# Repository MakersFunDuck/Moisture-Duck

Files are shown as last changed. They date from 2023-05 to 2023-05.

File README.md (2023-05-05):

# Moisture-Duck
ATtiny13A Resistive Soil Sensor for Duck Lovers

Moisture-Duck helps you keep track of your plants' soil moisture and alerts you if they need watering. It utilizes the resistance measurement technique to gauge soil moisture levels. Two probes, in combination with the substrate, constitute a variable resistor. Greater soil moisture translates to improved conductivity and decreased electrical resistance. With the addition of a 12k fixed resistor, the system creates a voltage divider. The microcontroller's ADC measures this voltage. The design is inspired by the SparkFun Soil Moisture Sensor.

Description:
------------
The Moisture Duck is a device that measures soil moisture and emits an acoustic and optical signal if the soil is too dry. The device is based on ATtiny13, which spends most of its time in sleep mode and wakes up every eight seconds to take measurements. It can also be activated by pressing the TEST button, and the correct threshold value can be set by turning the potentiometer. To calibrate the device, it should be placed in dry soil and the potentiometer should be adjusted until the alarm is triggered. The device is compiled using MicroCore and default settings should be left unchanged. Arduino core functions and libraries are not used, and the makefile can be used for compilation without Arduino IDE. The fuse settings are -U lfuse:w:0x3b:m -U hfuse:w:0xff:m.

Compiling and Uploading:
------------

You can program the ATtiny either before soldering using an SOP adapter, or after soldering using ICSP pins. The AVR Programmer Adapter can help with this.
If using the Arduino IDE

    Make sure you have installed MicroCore.
    Go to Tools -> Board -> MicroCore and select ATtiny13.
    Go to Tools and choose the following board options:
        Clock: 128 kHz internal osc.
        BOD: BOD disabled
        Timing: Micros disabled
    Connect your programmer to your PC and to the ATtiny.
    Go to Tools -> Programmer and select your ISP programmer (e.g. USBasp).
    Go to Tools -> Burn Bootloader to burn the fuses.
    Open main.ino and click Upload.

If using the precompiled hex-file

    Make sure you have installed avrdude.
    Connect your programmer to your PC and to the ATtiny.
    Open a terminal.
    Navigate to the folder with the hex-file.
    Execute the following command (if necessary replace "usbasp" with the programmer you use):

    avrdude -c usbasp -p t13 -U lfuse:w:0x3b:m -U hfuse:w:0xff:m -U flash:w:main.hex

If using the makefile (Linux/Mac)

    Make sure you have installed avr-gcc toolchain and avrdude.
    Connect your programmer to your PC and to the ATtiny.
    Open a terminal.
    Navigate to the folder with the makefile and sketch.
    Run PROGRMR=usbasp make install to compile, burn the fuses and upload the firmware (change PROGRMR accordingly).

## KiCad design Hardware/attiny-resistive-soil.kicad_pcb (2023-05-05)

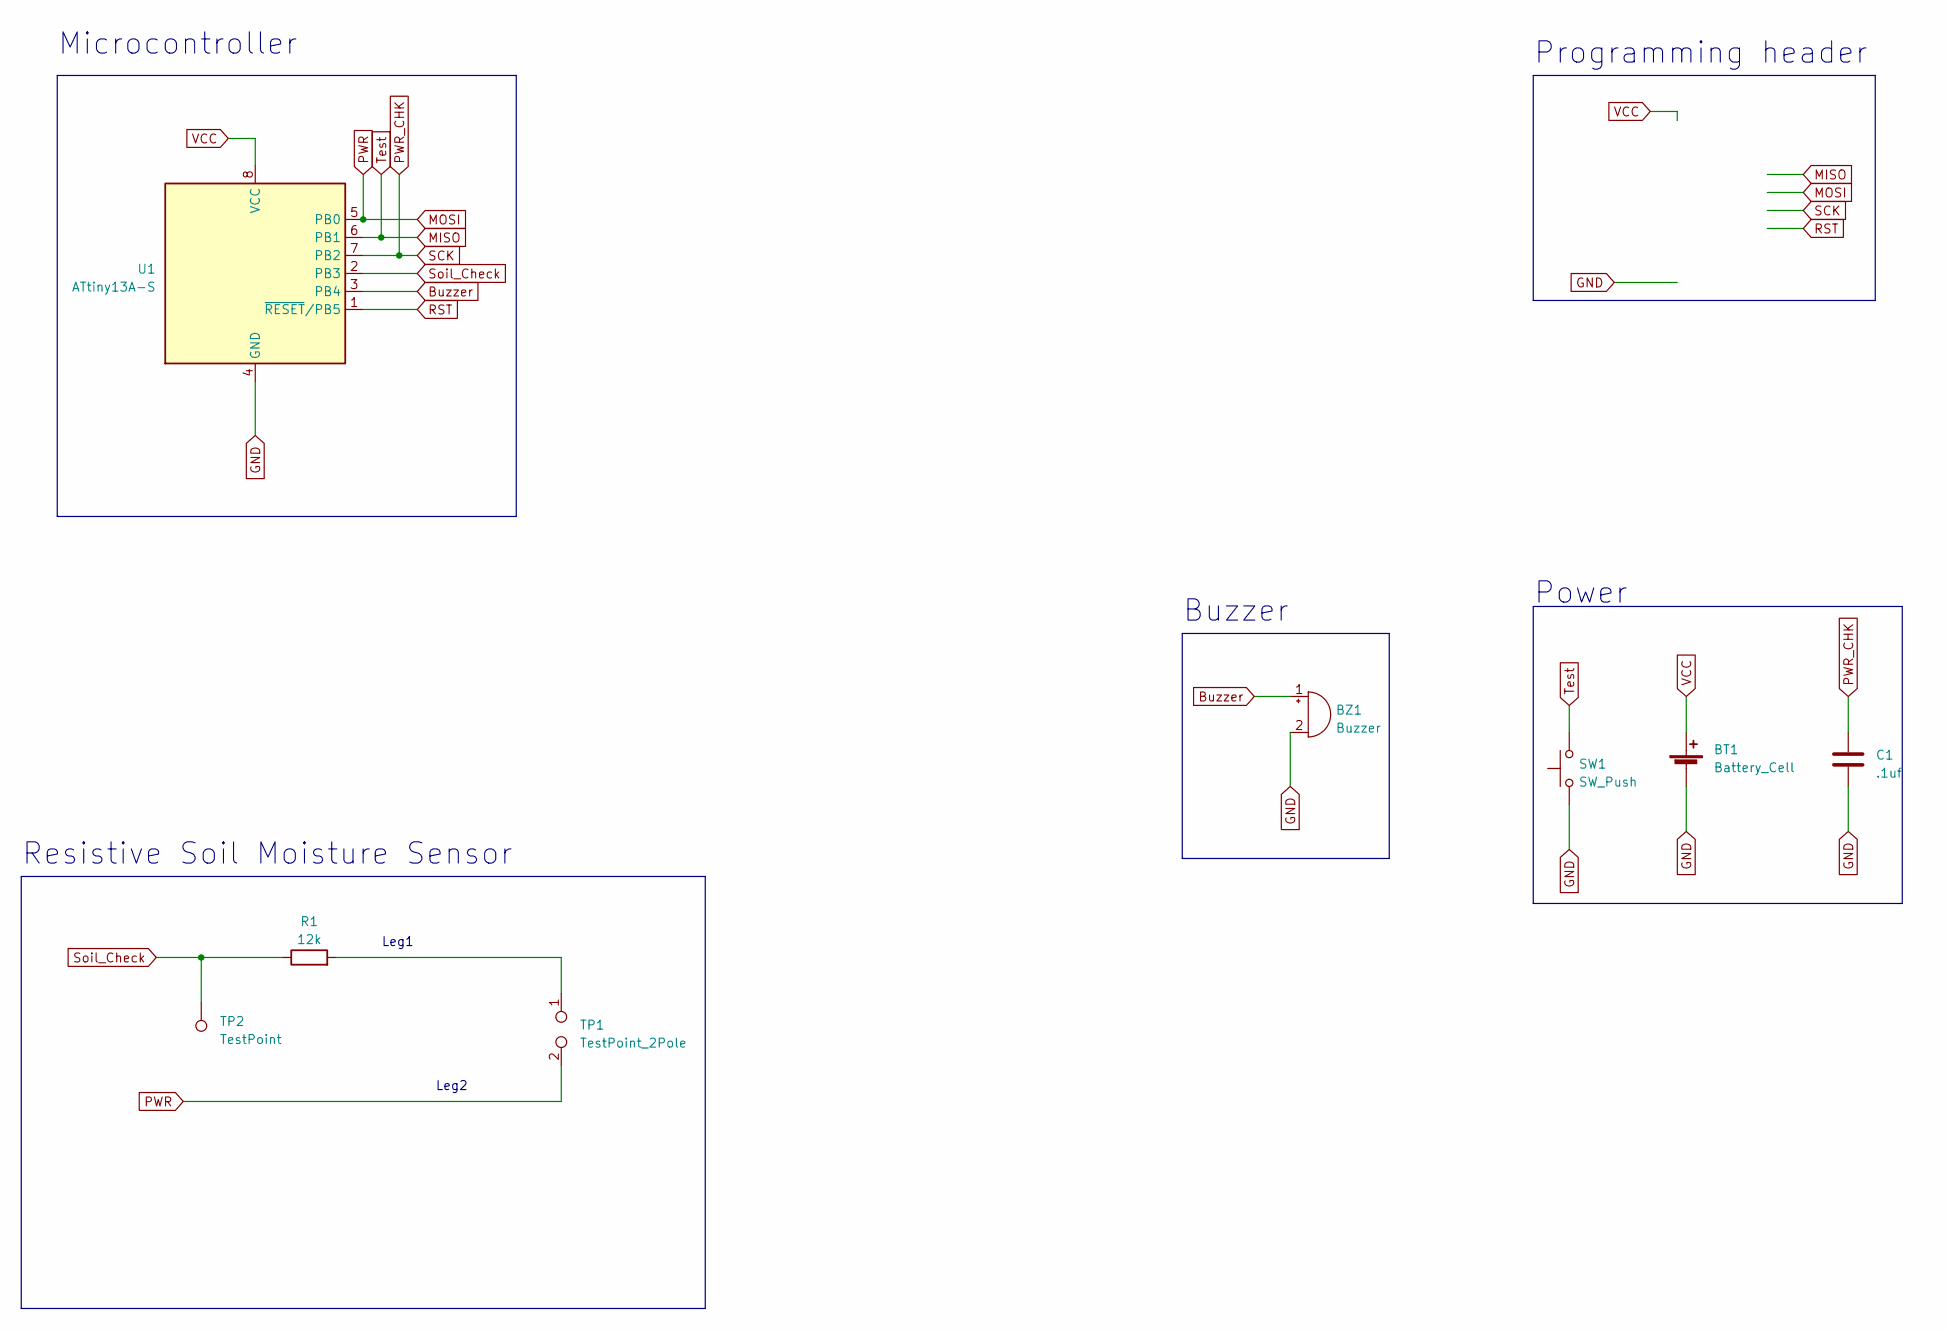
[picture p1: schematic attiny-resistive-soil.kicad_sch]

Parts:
BT1: Battery_Cell; BatteryHolder_Keystone_1060_1x2032
BZ1: Buzzer; MagneticBuzzer_CUI_CMT-8504-100-SMT
C1: .1uf; C_0805_2012Metric_Pad1.18x1.45mm_HandSolder
R1: 12k; R_0805_2012Metric_Pad1.20x1.40mm_HandSolder
SW1: SW_Push; SW_SPST_CK_RS282G05A3
TP1: TestPoint_2Pole; PinSocket_1x02_P2.54mm_Vertical
TP2: TestPoint; Pin_D1.4mm_L8.5mm_W2.8mm_FlatFork
U1: ATtiny13A-S; SOIC-8W_5.3x5.3mm_P1.27mm

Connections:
Buzzer: BZ1.1 (-), U1.3 (PB4)
GND: BT1.2 (-), BZ1.2 (+), C1.2, SW1.1, U1.4 (GND)
MISO: SW1.2, U1.6 (PB1)
MOSI: TP1.2, U1.5 (PB0)
unnamed: R1.2, TP1.1
PWR_CHK: C1.1, U1.7 (PB2)
RST: U1.1 (~RESET/PB5)
Soil_Check: R1.1, TP2.1, U1.2 (PB3)
VCC: BT1.1 (+), U1.8 (VCC)

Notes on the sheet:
Buzzer
Resistive Soil Moisture Sensor
Leg1
Programming header
Leg2
Microcontroller
Power

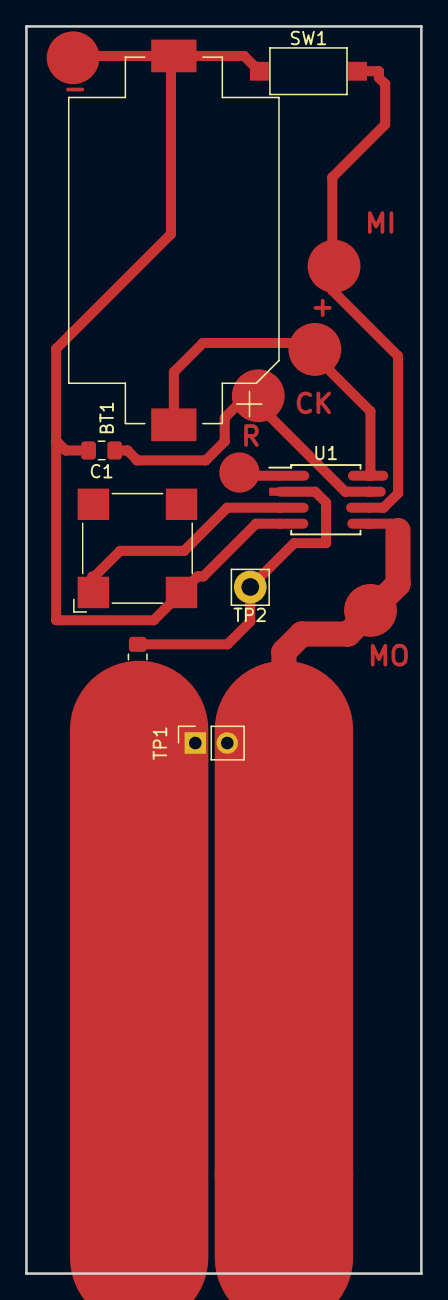
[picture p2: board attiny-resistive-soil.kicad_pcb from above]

Board: 2 copper layers, 31.4 x 99.1 mm, 8 parts (0 on the bottom side), 8 nets.

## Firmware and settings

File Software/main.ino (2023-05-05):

// ===================================================================================
// Project:   Moisture-Duck - Soil Moisture Monitor based on ATtiny13A
// Version:   v1.0
// Year:      2023
// Github:    https://github.com/MakersFunDuck
// Youtube:   https://www.youtube.com/@makersfunduck
// License:   GNU General Public License v3.0
// ===================================================================================
//
// Description:
// ------------
// The ATtiny13 is programmed to enter sleep mode for most of the time.
// It utilizes the watchdog timer to wake up every 2 minutes and measure soil moisture,
// comparing it to a preset threshold value.
// If the soil is too dry, it triggers a brief acoustic signal from the buzzer before going back to sleep mode.
//
// Additionally, the Moisture-Duck can also be activated by pressing the TEST button. (pin
// change interrupt).  It outputs an acoustic signal to indicate if the battery power is sufficient,
// followed by measurements of soil moisture until the button is released.

//
// To calibrate the Moisture-Duck, it should be placed in slightly dry soil,
// Then voltage 
//
// Wiring:
// -------
//                                +-\/-+
//   		   --- RST ADC0 PB5  1|°   |8  Vcc
//  Soil_Check ------- ADC3 PB3  2|    |7  PB2 ADC1 -------- PWR_CHK
// 	BUZZER ----------- ADC2 PB4  3|    |6  PB1 AIN1 OC0B --- TEST
//                          GND  4|    |5  PB0 AIN0 OC0A --- PWR
//                                +----+
//
// Compilation Settings:
// ---------------------
// Controller:  ATtiny13A
// Core:        MicroCore (https://github.com/MCUdude/MicroCore)
// Clockspeed:  128 kHz internal
// BOD:         BOD disabled
// Timing:      Micros disabled
//
// You can keep the other default settings as they are.  Don't forget to "Burn bootloader"!
// before proceeding.
// There are no Arduino core functions or libraries incorporated in this project. 
// You can use the makefile for compiling without the Arduino IDE.
// To program without Arduino IDE Fuse settings are: -U lfuse:w:0x3b:m -U hfuse:w:0xff:m



// ===================================================================================
// Libraries and Definitions
// ===================================================================================

// Libraries
#include <avr/io.h>             // for gpio
#include <avr/sleep.h>          // for the sleep modes
#include <avr/interrupt.h>      // for the interrupts
#include <avr/wdt.h>            // for the watch dog timer
#include <util/delay.h>         // for delays




// Pin definitions
#define PWR_PIN  PB0        // power pin output
#define BUZZER_PIN  PB4       // buzzer pin output
#define TEST_PIN  PB1       // test button input
#define SOIL_PIN  PB3       // Soil  pin input
#define PWR_CHK  PB2        // battery check input

// ADC port definitions
#define Soil_Check  3               // ADC port of measurement
#define VCC_Check  2        // ADC port of measurement

uint8_t count = 0;          //Watchdog counter
#define V_REF 1100          // internal reference voltage in mV

//Functions
void resetWatchdog(void);
void sleep(void);
uint8_t get_vcc(void);
void beep(int num_times);
uint16_t readADC(uint8_t port);
void delay_ms(uint16_t ms);

uint8_t vcccount = 0; //VCC measurement count


// ===================================================================================
// Watchdog and Sleep Implementation
// ===================================================================================



// Reset watchdog timer
void resetWatchdog(void) {
  cli();                                  // timed sequence coming up
  wdt_reset();                            // reset watchdog
  MCUSR = 0;                              // clear various "reset" flags
  WDTCR = (1<<WDCE)|(1<<WDE)|(1<<WDTIF);  // allow changes, disable reset
  WDTCR = (1<<WDTIE)|(1<<WDP3)|(1<<WDP0); // set WDT interval 8 seconds
  sei();                                  // interrupts are required now
      
  
}

// Go to sleep in order to save energy, wake up by watchdog timer or pin change interrupt
void sleep(void) {
  GIFR |= (1<<PCIF);                      // clear any outstanding interrupts
  resetWatchdog();                        // get watchdog ready
  sleep_mode();                           // sleep
}





// ===================================================================================
// Additional Functions
// ===================================================================================

void beep(int num_times) {
  for (int i = 0; i < num_times; i++) {
    for (int j = 0; j < 80; j++) {
      PORTB |= (1 << BUZZER_PIN);  // turn on the buzzer
      _delay_us(100);              // wait for 100 ms
      PORTB &= ~(1 << BUZZER_PIN); // turn off the buzzer
      _delay_us(100);              // wait for 100 ms
      }
    _delay_ms(100);
  }
}


// Analog read ADC
uint16_t readADC(uint8_t port) {
  ADMUX   = (port & 0x03);                // set port against Vcc
  ADCSRA |= (1<<ADSC);                    // start ADC conversion
  while(ADCSRA & (1<<ADSC));              // wait for ADC conversion complete
  return(ADC);                            // read and return measurement
}

// Analog read VCC 
//0,1uF capacitor first will be charged, and soil check pin ADC value will be read
uint16_t readVCC() {
   DDRB |= (1 << PWR_CHK);         // Set PWR_CHK as output
   PORTB |= (1 << PWR_CHK);       // Set PWR_CHK high
   _delay_ms(50);              // Wait for charging
   //DDRB |= ~(1 << PWR_CHK);   // Set PWR_CHK as input
  return readADC(VCC_Check);
  //PORTB &= ~(1 << PWR_CHK);  // Set PWR_CHK low
  //DDRB |= ~(1 << PWR_CHK);   // Set PWR_CHK as input
  
}


// Timer/Counter0 Compare Match A interrupt handler
ISR(TIM0_COMPA_vect)
{
  // Decrement timer value
  OCR0A--;
}
// Watchdog interrupt service routine
ISR(WDT_vect) {
  wdt_disable();                          // disable watchdog
  if (count > 15) // if interrupted 15. times ( after 15*8sec = 120s = 2min )
    {
      count = 0;      
    }
  else{
    count++;
    sleep();
    }
}



// ===================================================================================
// Main Function
// ===================================================================================

int main(void) {
  
  // Reset watchdog timer
  resetWatchdog();                        // do this first in case WDT fires

  // Disable unused peripherals and set sleep mode to save power
  ACSR   = (1<<ACD);                      // disable analog comparator
  DIDR0 |= (1<<SOIL_PIN )|(1<<PWR_CHK);   // disable digital input buffer on ADC pins

  // Setup pins
  DDRB  = (1<<BUZZER_PIN)|(1<<PWR_PIN);       // set output pins
  PORTB = (1<<TEST_PIN);                  // set pull-ups

  set_sleep_mode(SLEEP_MODE_PWR_DOWN);    // set sleep mode to power down

  // Setup pin change interrupt
  GIMSK = (1<<PCIE);                      // pin change interrupts enable
  PCMSK = (1<<TEST_PIN);                  // set pins for pin change interrupt
  sei();                  // enable global interrupts
       
                                
  
  
  // Loop
  while(1) {
    
    if(~PINB & (1<<TEST_PIN))   beep(1);        // alarm if test button is pressed
    ADCSRA |=  (1<<ADEN);               // enable ADC
    //if (vcccount < 15) vcccount = vcccount++;     // don't always read the vcc  to save energy
    //if (vcccount > 15){
        //uint16_t vcc = readVCC(); 
        //if (vcc<1768) beep(8);            //battery low alarm
        
    /*  
    
    Voltage = ADC_value * Vref / 1024
    = 1768 * 1.1V / 1024
    = 1,89V
    */        
     // vcccount = 0;
     // }
          
     PORTB  |=  (1<<PWR_PIN);          // power measurement circuit
     _delay_us(125);              // give it all a little time  
    do {
      if((readADC(Soil_Check)) < 512   )beep(2);  // beep twice if dry soil
    } while(~PINB & (1<<TEST_PIN));         // repeat if test button is hold
      
    /*
    
    Voltage = ADC_value * Vref / 1024
    = 512 * 1.1V / 1024
    = 0.55V
    */
    
    PORTB  &= ~(1<<PWR_PIN)|~(1<<SOIL_PIN);         // power off to prevent corrosion   
    ADCSRA &= ~(1<<ADEN);         // disable ADC
    sleep();                // sleep for a while ...
  }
}
